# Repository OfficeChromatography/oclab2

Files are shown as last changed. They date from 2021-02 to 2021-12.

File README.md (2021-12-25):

# OCLab2
## Next Generation Office Chromatography

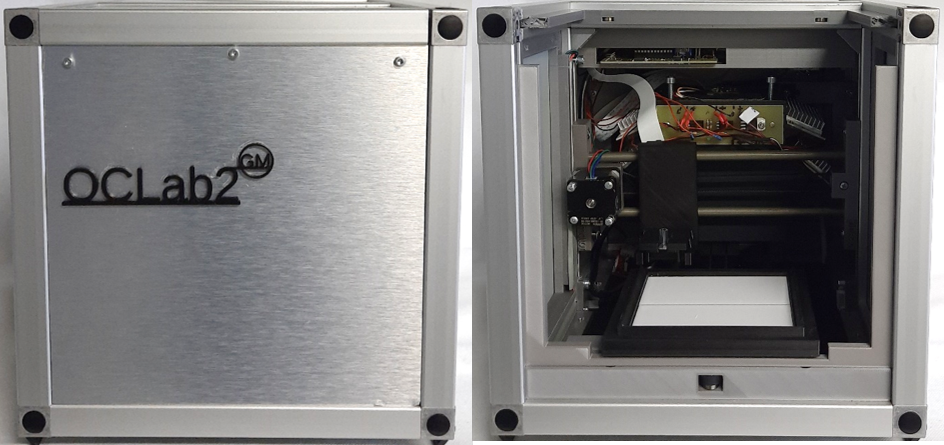
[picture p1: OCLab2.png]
OCLab2


The former [OCLab prototype](https://github.com/OfficeChromatography/OCLab) of a “miniaturized all-in-one open
 source system for planar chromatography” was upgraded by an HPTLC plate visualizing cabinet to protect the 
 plate from extraneous light during capturing of images, including RGBW, UV 278 nm and UV 366 nm LED boards 
 as well as a Raspberry Pi V2 camera module. 
 
 Additionally, a newly designed printhead was manufactured, 
 controlled by a self-constructed ink-jet board allowing to check the nozzles’ resistance heating circuit. 
 Furthermore, plate heating was enabled, especially favorable when higher volumes of aqueous samples are to 
 be applied. 
 
 The former [OC Manager software](https://github.com/OfficeChromatography/OC_manager) was completely 
 restructured and newly written in R to speed-up the processes ([OC_manager2](https://github.com/OfficeChromatography/oc_manager2))
 , also supported by the new Raspberry Pi 4B computer with 4 GB RAM .

### Hardware/Firmware
The 3D printed parts are in the folder 'Construction Set', the electronic boards are described in the folder 
'Eagle Files', and the modified firmware is available in the folder 'Marlin'.
Assembly instructions are in the folder 'Instruction'.

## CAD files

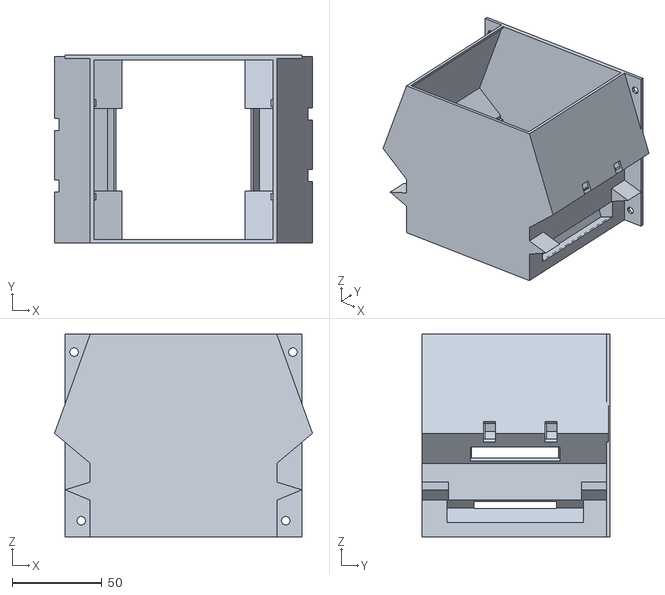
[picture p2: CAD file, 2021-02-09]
Construction Set/camera_tower/STL/camera_tower.stl
143.8 x 105.0 x 113.0

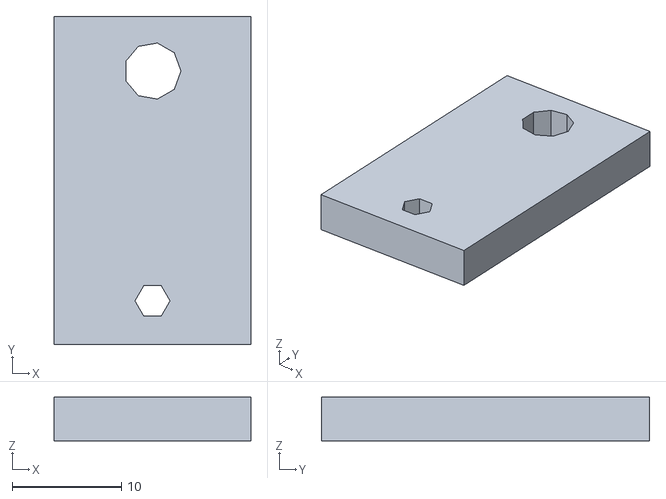
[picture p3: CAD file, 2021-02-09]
Construction Set/connectors/plate_heating_connector.stl
18.0 x 30.0 x 4.00

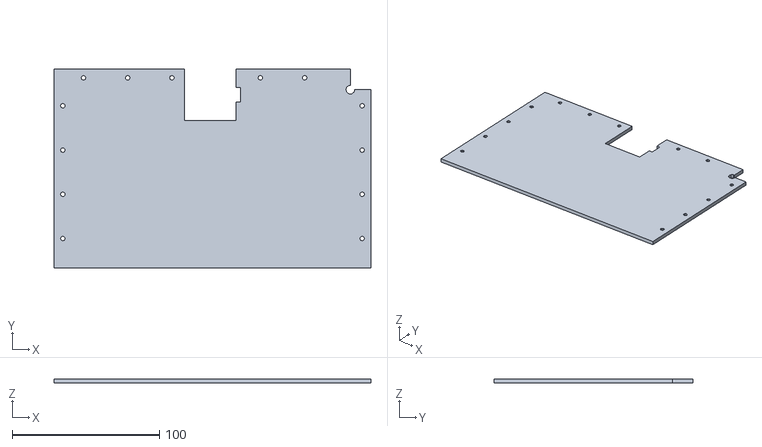
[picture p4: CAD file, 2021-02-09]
Construction Set/faces_frames/STL/bottom_plate_back.stl
215.0 x 135.0 x 3.00

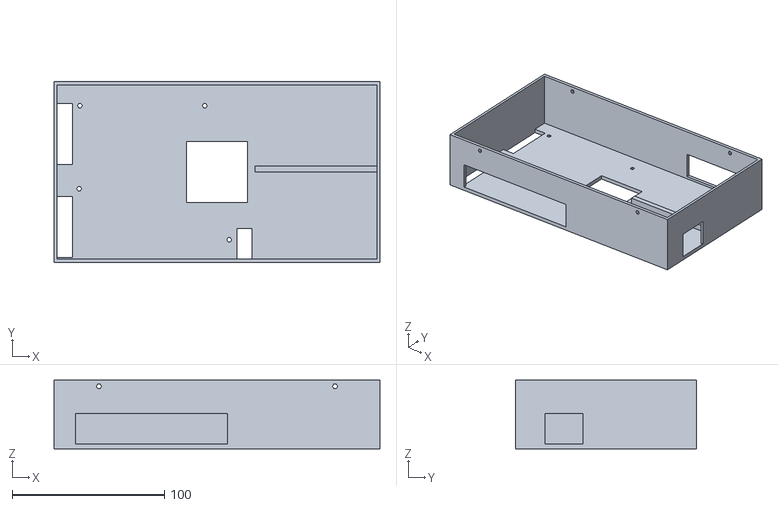
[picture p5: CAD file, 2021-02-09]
Construction Set/housing_electronics/housing_electronics.stl
214.0 x 119.0 x 45.0

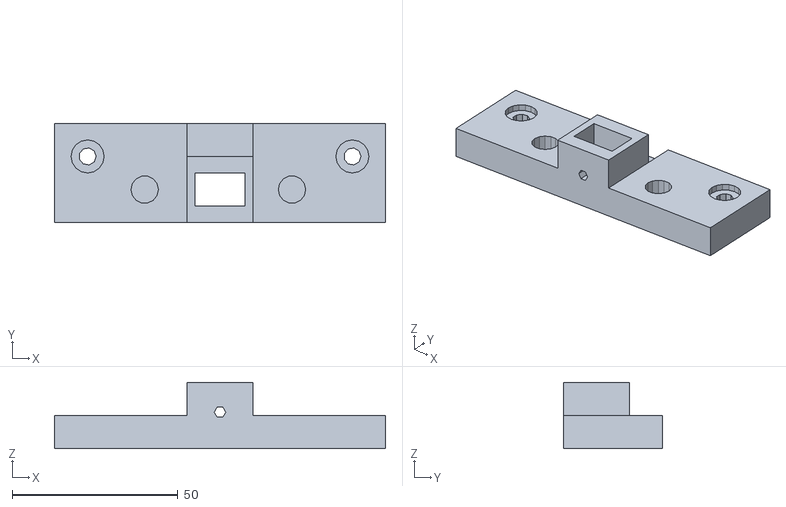
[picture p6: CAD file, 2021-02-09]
Construction Set/X_moving/STL/X_end.stl
100.0 x 30.0 x 20.0

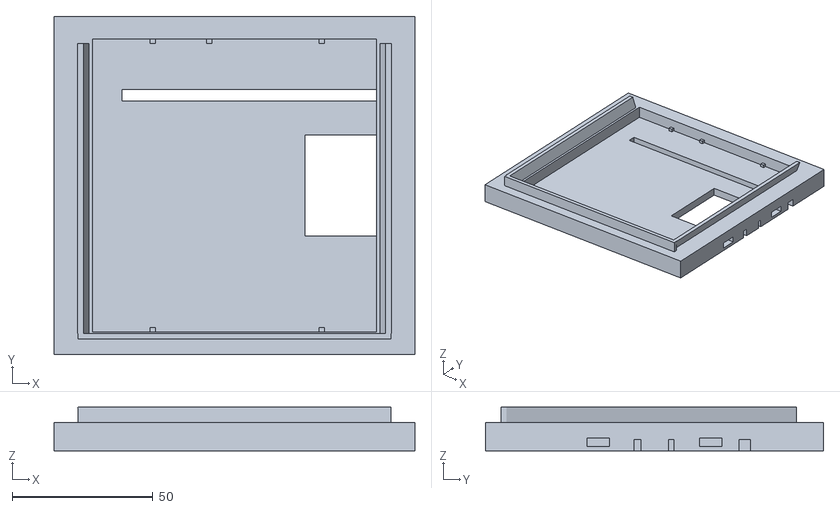
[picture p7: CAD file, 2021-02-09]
Construction Set/Y_moving/STL/plateholder_heating_mat_tower_frame.stl
128.0 x 120.0 x 15.5

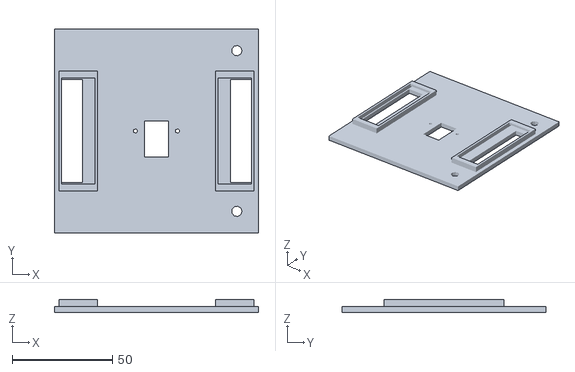
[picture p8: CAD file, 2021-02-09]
Construction Set/camera_tower/STL/camera_holder.stl
101.6 x 101.6 x 6.50

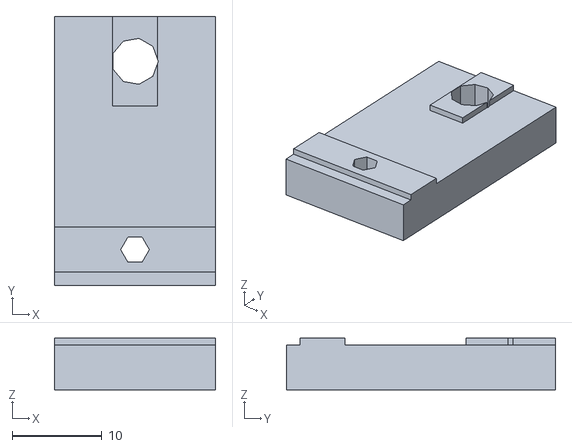
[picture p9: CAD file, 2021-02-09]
Construction Set/connectors/connector_Z_axis_center.stl
18.0 x 30.0 x 5.75

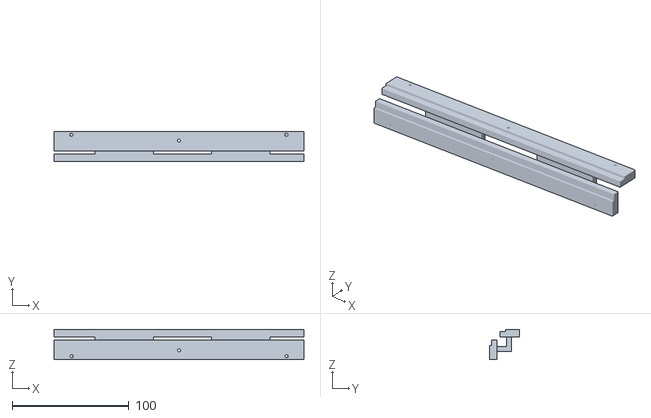
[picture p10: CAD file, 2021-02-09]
Construction Set/faces_frames/STL/cover_mounting.stl
214.0 x 26.0 x 26.0

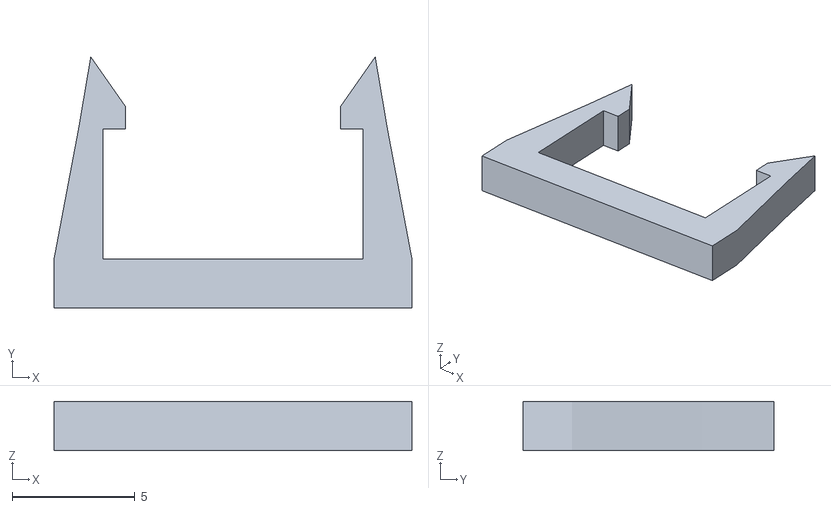
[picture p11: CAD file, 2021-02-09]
Construction Set/X_moving/STL/printhead_clamp.stl
14.6 x 10.2 x 2.00

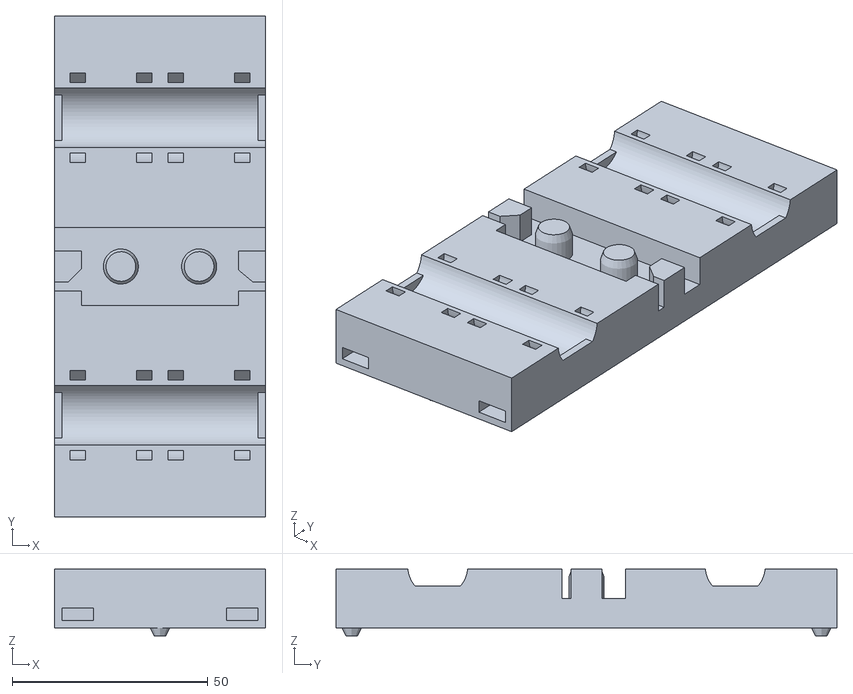
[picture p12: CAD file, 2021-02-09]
Construction Set/Y_moving/STL/Y_moving.stl
54.0 x 128.0 x 17.0

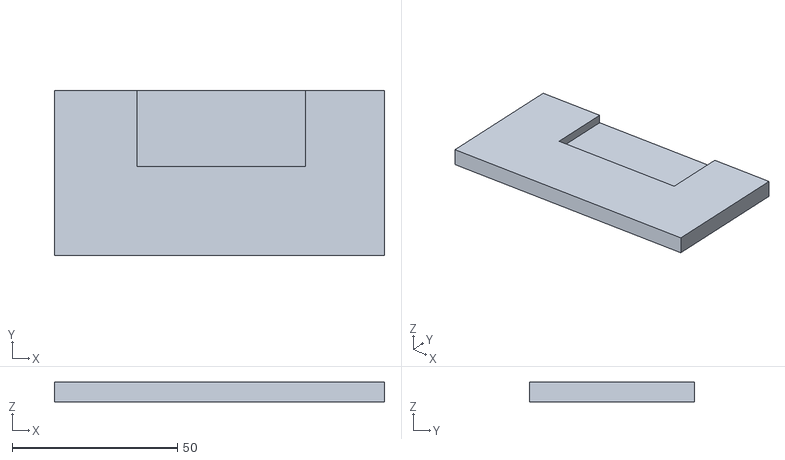
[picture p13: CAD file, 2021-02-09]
Construction Set/camera_tower/STL/cutting_aid_HU02_filter.stl
100.0 x 50.0 x 6.00

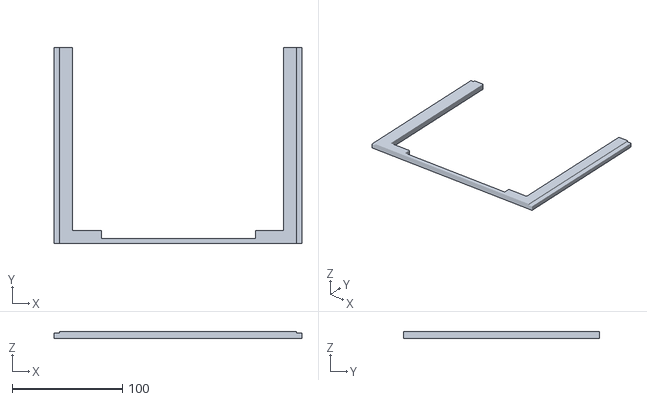
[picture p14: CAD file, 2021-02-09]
Construction Set/faces_frames/STL/front.stl
225.0 x 178.0 x 6.50

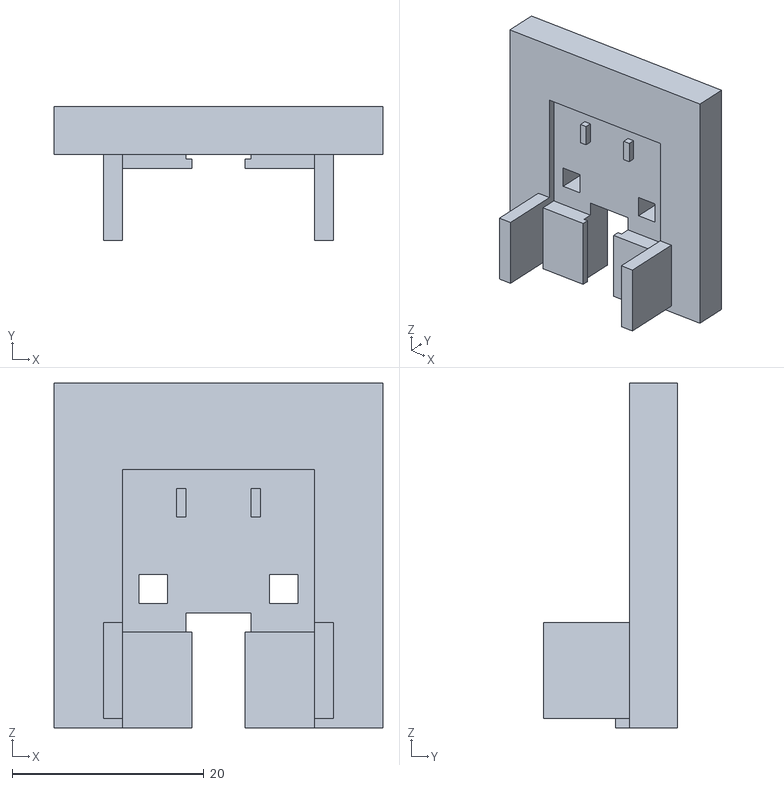
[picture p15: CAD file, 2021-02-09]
Construction Set/X_moving/STL/printhead_top.stl
34.3 x 14.0 x 36.0

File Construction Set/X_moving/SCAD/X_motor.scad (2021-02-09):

// X_motor

difference() {
    start();
    translate([50, 25, 0]) cube([35, 10, 35], center=true);
    translate([27.25,10,4.5])
      cylinder (h = 30, r=4.15); //hole for 8-mm rod
    translate([71.75,10,4.5])
      cylinder (h = 30, r=4.15); //hole for 8-mm rod
    translate([42.5,10,26])
      cube([15,3,9]);
    rotate([90,0,0]) translate([50,17.5,-25])
      cylinder(h=30, r=12.5); //hole for motor
    translate([10,20,-10])
      cylinder (h = 30, r = 2.6); //M5 screw
    translate([90,20,-10])
      cylinder ( h=30, r=2.6); //M5 screw
//Sinkings for M5 screws
    translate([10,20,8])
      cylinder (h=10, r=5);
    translate([90,20,8])
      cylinder (h=10, r=5);
//Screws for motor Nema 14
    rotate([90,0,0]) translate([36.5,4.5,-25])
      cylinder (h=30, r=1.6);
    rotate([90,0,0]) translate([62.5,4.5,-25])
      cylinder (h=30, r=1.6);
    rotate([90,0,0]) translate([36.5,30.5,-25])
      cylinder (h=30, r=1.6);
    rotate([90,0,0]) translate([62.5,30.5,-25])
      cylinder (h=30, r=1.6);
//Sinkings for motor screws
    rotate([90,0,0]) translate([36.5,4.5,-12])
      cylinder (h=20, r=3.5);
    rotate([90,0,0]) translate([62.5,4.5,-12])
      cylinder (h=20, r=3.5);
    rotate([90,0,0]) translate([36.5,30.5,-12])
      cylinder (h=20, r=3.5);
    rotate([90,0,0]) translate([62.5,30.5,-12])
      cylinder (h=20, r=3.5);
//Port for endstop  
    translate([0,11,6])
      cube([22,1.7,4]);
}

module start(){
    cube([100,30,10]);
    translate([32,10,0])
     cube([35,10,35]);
}   

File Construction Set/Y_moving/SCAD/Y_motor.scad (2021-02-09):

// Y_motor Nema 14

x=215;
 
difference() {
    start();
    cube([215, 20, 6]);
    color("yellow", 1.0) {    
    //Holes for rods
    translate([68,10,9.5])
    cylinder (h = 20, r=4.15);
    translate([144, 10, 9.5])
    cylinder (h = 20, r=4.15);
}    
//Hole for motor
color("blue", 1.0 ) {
    rotate([90,0,0])
    translate([109,37.5,-25])
    cylinder(h=30, r=12.5);}
//Holes for M4 screws
color( "black", 1.0) {
    rotate([90,0,0])
    translate([50,10,-30])
    cylinder (h = 40, r = 2.1);
    rotate([90,0,0])
    translate([x-50,10,-30])
    cylinder (h=40, r=2.1);
//Sinkings for M4 screws
    rotate([90,0,0])
    translate([50,10,-6])
    cylinder (h = 6, r=3.6);
    rotate([90,0,0])
    translate([x-50,10,-6])
    cylinder (h=6, r=3.6);    
//Holes for M3 screws, motor mounting
    rotate([90,0,0])
    translate([96,24.5,-25])
    cylinder (h=30, r=1.75);
    rotate([90,0,0])
    translate([122,24.5,-25])
    cylinder (h=30, r=1.75);
    rotate([90,0,0])
    translate([96,50.5,-25])
    cylinder (h=30, r=1.75);
    rotate([90,0,0])
    translate([122,50.5,-25])
    cylinder (h=30, r=1.75); }
//Sinkings for M3 screws
    rotate([90,0,0])
    translate([96,24.5,-13])
    cylinder (h=20, r=3.5);
    rotate([90,0,0])
    translate([122,24.5,-13])
    cylinder (h=20, r=3.5);
    rotate([90,0,0])
    translate([96,50.5,-13])
    cylinder (h=20, r=3.5);
    rotate([90,0,0])
    translate([122,50.5,-13])
    cylinder (h=20, r=3.5);
}
module start(){
cube([215,20,20]);
        color( "red", 1.0 ){
        translate([91.5,10,20])
        cube([35,10,35]);}
}  

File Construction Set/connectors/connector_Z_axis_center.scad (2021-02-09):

//Connector Z_axis center

difference() {
    start();
        translate([0, -11, -5])
        cylinder (h=10, r=1.6);
    translate([0, 10, -5])
    cylinder (h=10, r=2.6);
}
module start() {
    cube([18, 30, 5], center = true);
        translate([0, -11, 2.5])
        cube([18, 5, 1.5], center=true);
        translate([0, 10, 2.5])
        rotate([0, 0, 90])
        cube([10, 5, 1.5], center=true);
    }

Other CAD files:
Construction Set/Y_moving/STL/tower_distance_check.stl
Construction Set/camera_tower/STL/mounting_frame.stl
Construction Set/faces_frames/STL/back_top.stl
Construction Set/X_moving/STL/X_moving.stl
Construction Set/connectors/plate_heating_connector.scad
Construction Set/X_moving/SCAD/HelpMethods/AntiSupport.scad
Construction Set/X_moving/SCAD/HelpMethods/SnapLib.0.36.scad
Construction Set/X_moving/SCAD/HelpMethods/bearing.scad
Construction Set/X_moving/SCAD/HelpMethods/bearing_hor.scad
Construction Set/X_moving/SCAD/HelpMethods/beltholder.scad
Construction Set/X_moving/SCAD/HelpMethods/holder_triangle.scad
Construction Set/X_moving/SCAD/HelpMethods/polyholes.scad
Construction Set/X_moving/SCAD/HelpMethods/supporting_material.scad
Construction Set/X_moving/SCAD/HelpMethods/triangle.scad
Construction Set/X_moving/SCAD/X_end.scad
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

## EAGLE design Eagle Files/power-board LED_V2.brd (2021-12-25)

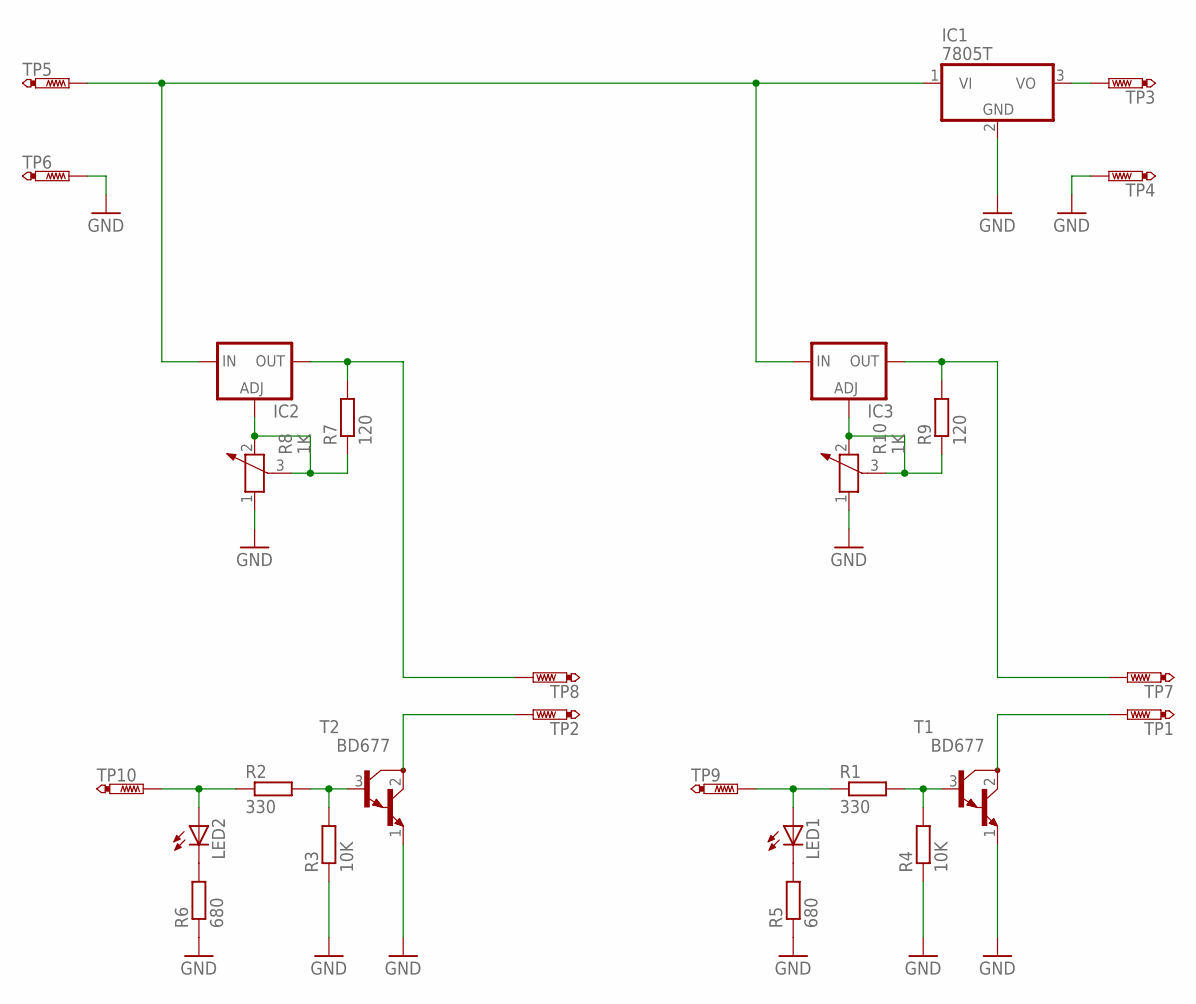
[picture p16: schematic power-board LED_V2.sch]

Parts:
IC1: 7805T; TO220H
IC2, IC3: LM317TS; 317TS
LED1, LED2: LED3MM
R1, R2: 330; 0207/10
R3, R4: 10K; 0207/10
R5, R6: 680; 0207/10
R7, R9: 120; 0207/10
R8, R10: 1K; PT-10
T1, T2: BD677; TO126
TP1, TP2, TP3, TP4, TP5, TP6, TP7, TP8, TP9, TP10: PTR1PAD1-17; P1-17

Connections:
GND: IC1.2 (GND), R3.1, R4.1, R5.1, R6.1, R8.1, R10.1, T1.1 (E), T2.1 (E), TP4.TP, TP6.TP
unnamed: R1.2, R4.2, T1.3 (B)
unnamed: LED1.A, R1.1, TP9.TP
unnamed: T1.2 (C), TP1.TP
unnamed: R2.2, R3.2, T2.3 (B)
unnamed: LED2.A, R2.1, TP10.TP
unnamed: T2.2 (C), TP2.TP
unnamed: IC1.3 (VO), TP3.TP
unnamed: LED1.K (C), R5.2
unnamed: LED2.K (C), R6.2
unnamed: IC2.1 (ADJ), R7.1, R8.2, R8.3
unnamed: IC3.1 (ADJ), R9.1, R10.2, R10.3
unnamed: IC3.2 (OUT), R9.2, TP7.TP
unnamed: IC2.2 (OUT), R7.2, TP8.TP
unnamed: IC1.1 (VI), IC2.3 (IN), IC3.3 (IN), TP5.TP

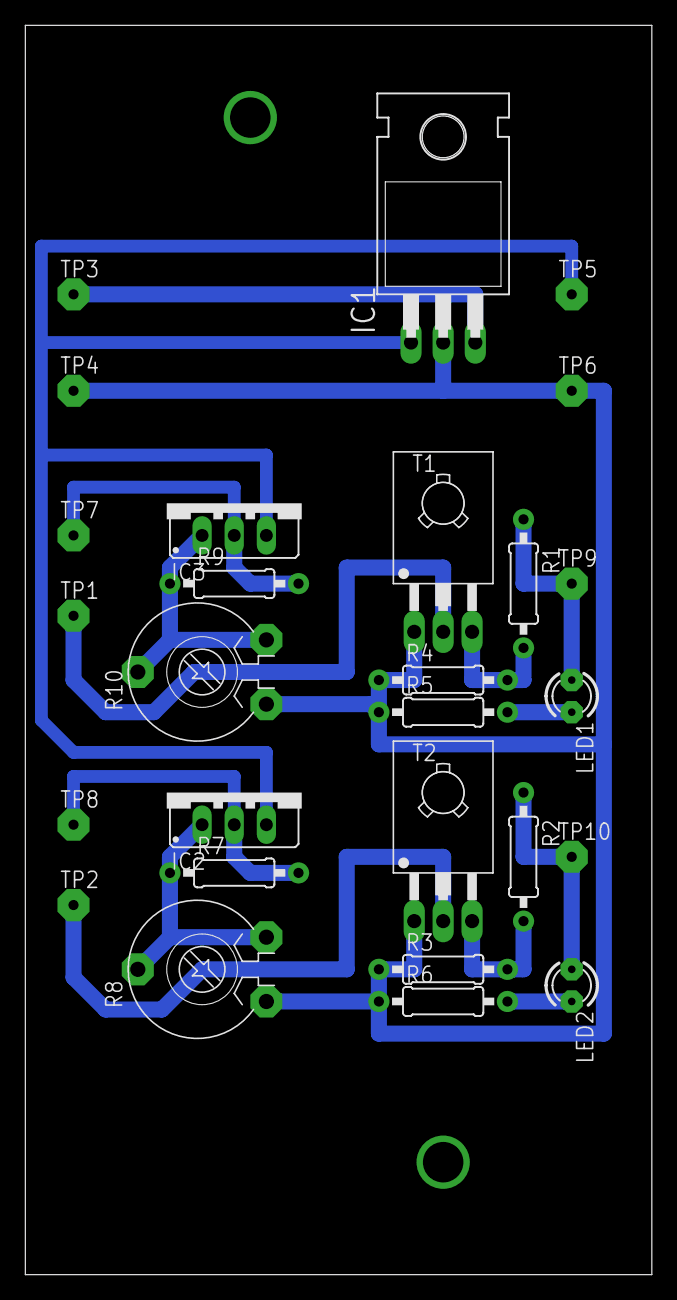
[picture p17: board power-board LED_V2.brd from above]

Board: 2 copper layers, 49.5 x 98.7 mm, 27 parts (0 on the bottom side), 15 nets.

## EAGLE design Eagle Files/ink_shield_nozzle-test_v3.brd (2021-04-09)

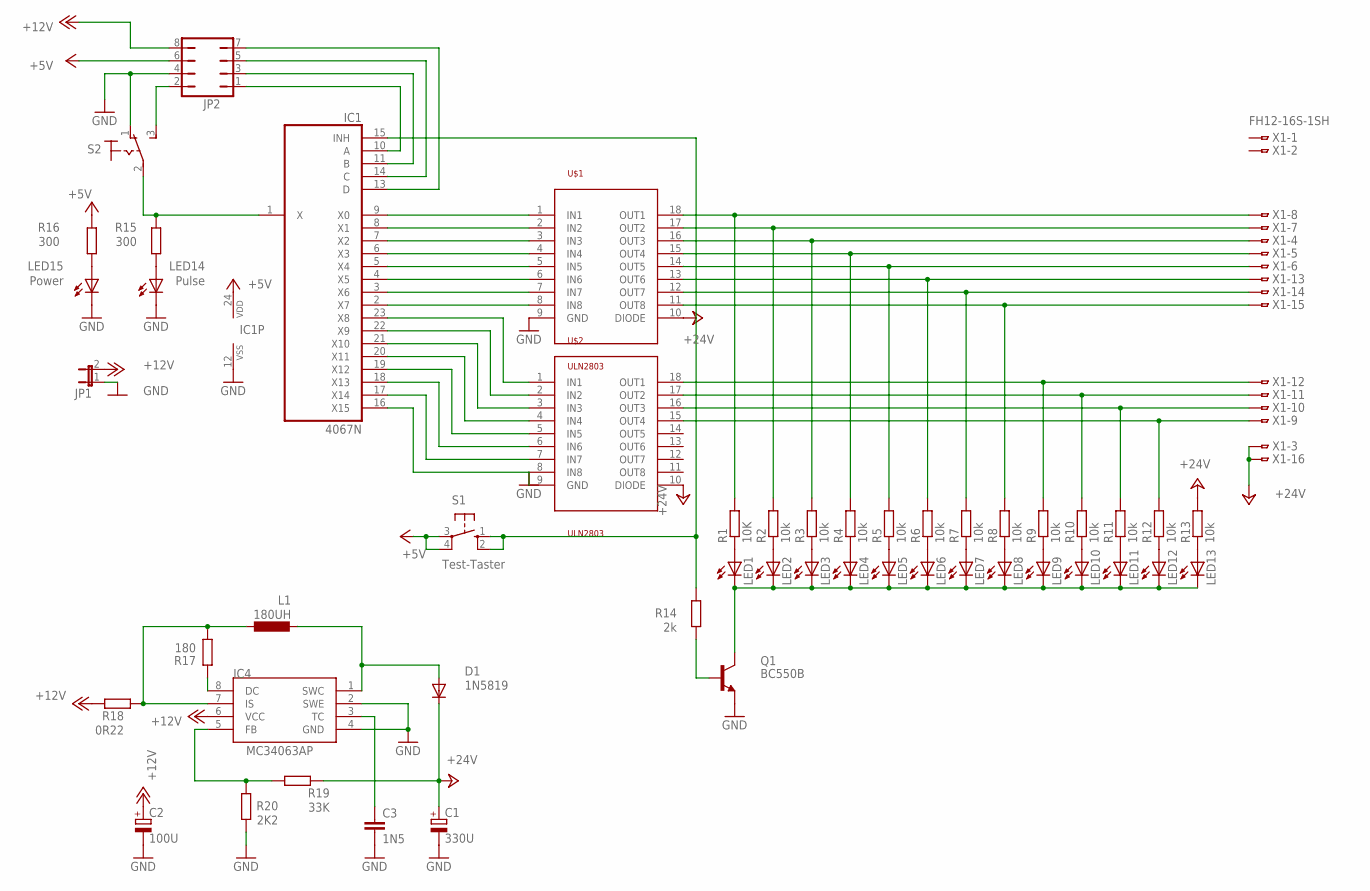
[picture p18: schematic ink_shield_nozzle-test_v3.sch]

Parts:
C1: 330U; E3,5-10
C2: 100U; E2,5-6
C3: 1N5; C025-024X044
D1: 1N5819; DO35-10
IC1: 4067N; DIL24-6
IC4: MC34063AP; DIL08
JP1: JP1E; JP1
JP2: JP4Q
L1: 180UH; 6000-XXXX-RC
LED1, LED2, LED3, LED4, LED5, LED6, LED7, LED8, LED9, LED10, LED11, LED12, LED13: LEDCHIPLED_0603; CHIPLED_0603
LED14: Pulse; LED3MM
LED15: Power; LED3MM
Q1: BC550B; TO92-EBC
R1: 10K; M1206
R2, R3, R4, R5, R6, R7, R8, R9, R10, R11, R12, R13: 10k; M1206
R14: 2k; M3216
R15, R16: 300; 0207/10
R17: 180; 0207/12
R18: 0R22; 0207/12
R19: 33K; 0207/12
R20: 2K2; 0207/10
S1: Test-Taster; B3F-10XX
S2: M9040P
U$1, U$2: ULN2803; SO18L
X1: FH12-16S-1SH

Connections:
+5V: IC1.24 (VDD), JP2.6, R16.2, S1.3, S1.4 (P1)
+12V: C2.+, IC4.6 (VCC), JP1.2, JP2.8, R18.2
+24V: C1.+, D1.C, R13.2, R19.1, U$1.10 (DIODE), U$2.10 (DIODE), X1.3, X1.16
GND: C1.-, C2.-, C3.2, IC1.12 (VSS), IC4.2 (SWE), IC4.4 (GND), JP1.1, JP2.4, LED14.K (C), LED15.K (C), Q1.E, R20.1, S2.1 (O), U$1.9 (GND), U$2.9 (GND)
unnamed: IC1.9 (X0), U$1.1 (IN1)
unnamed: IC1.8 (X1), U$1.2 (IN2)
unnamed: IC1.7 (X2), U$1.3 (IN3)
unnamed: IC1.6 (X3), U$1.4 (IN4)
unnamed: IC1.5 (X4), U$1.5 (IN5)
unnamed: IC1.4 (X5), U$1.6 (IN6)
unnamed: IC1.3 (X6), U$1.7 (IN7)
unnamed: IC1.2 (X7), U$1.8 (IN8)
unnamed: IC1.23 (X8), U$2.1 (IN1)
unnamed: IC1.22 (X9), U$2.2 (IN2)
unnamed: IC1.21 (X10), U$2.3 (IN3)
unnamed: IC1.20 (X11), U$2.4 (IN4)
unnamed: IC1.19 (X12), U$2.5 (IN5)
unnamed: IC1.18 (X13), U$2.6 (IN6)
unnamed: IC1.17 (X14), U$2.7 (IN7)
unnamed: IC1.16 (X15), U$2.8 (IN8)
unnamed: LED1.A, R1.1
unnamed: LED2.A, R2.1
unnamed: LED3.A, R3.1
unnamed: LED4.A, R4.1
unnamed: LED5.A, R5.1
unnamed: LED6.A, R6.1
unnamed: LED7.A, R7.1
unnamed: LED8.A, R8.1
unnamed: LED9.A, R9.1
unnamed: LED10.A, R10.1
unnamed: LED11.A, R11.1
unnamed: LED12.A, R12.1
unnamed: LED1.C, LED2.C, LED3.C, LED4.C, LED5.C, LED6.C, LED7.C, LED8.C, LED9.C, LED10.C, LED11.C, LED12.C, LED13.C, Q1.C
unnamed: R1.2, U$1.18 (OUT1), X1.8
unnamed: R2.2, U$1.17 (OUT2), X1.7
unnamed: R3.2, U$1.16 (OUT3), X1.4
unnamed: R4.2, U$1.15 (OUT4), X1.5
unnamed: R5.2, U$1.14 (OUT5), X1.6
unnamed: R6.2, U$1.13 (OUT6), X1.13
unnamed: R7.2, U$1.12 (OUT7), X1.14
unnamed: R8.2, U$1.11 (OUT8), X1.15
unnamed: R9.2, U$2.18 (OUT1), X1.12
unnamed: R10.2, U$2.17 (OUT2), X1.11
unnamed: R11.2, U$2.16 (OUT3), X1.10
unnamed: R12.2, U$2.15 (OUT4), X1.9
unnamed: LED13.A, R13.1
unnamed: IC1.15 (INH), R14.2, S1.1 (S), S1.2 (S1)
unnamed: Q1.B, R14.1
unnamed: LED14.A, R15.1
unnamed: IC1.10 (A), JP2.1
unnamed: IC1.11 (B), JP2.3
unnamed: IC1.14 (C), JP2.5
unnamed: IC1.13 (D), JP2.7
unnamed: IC1.1 (X), R15.2, S2.2
unnamed: LED15.A, R16.1
unnamed: IC4.7 (IS), L1.1, R17.2, R18.1
unnamed: D1.A, IC4.1 (SWC), L1.2
unnamed: IC4.8 (DC), R17.1
unnamed: C3.1, IC4.3 (TC)
unnamed: IC4.5 (FB), R19.2, R20.2
unnamed: JP2.2, S2.3 (S)

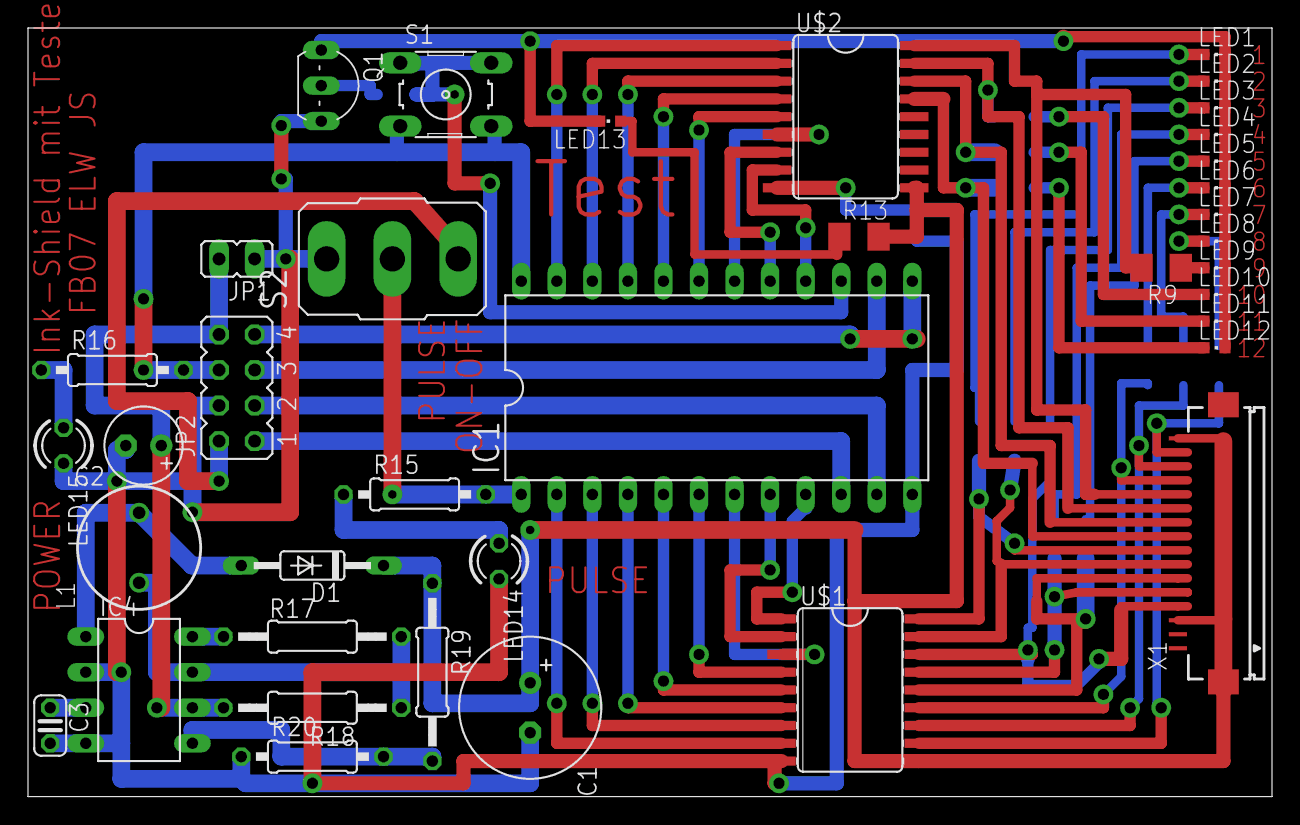
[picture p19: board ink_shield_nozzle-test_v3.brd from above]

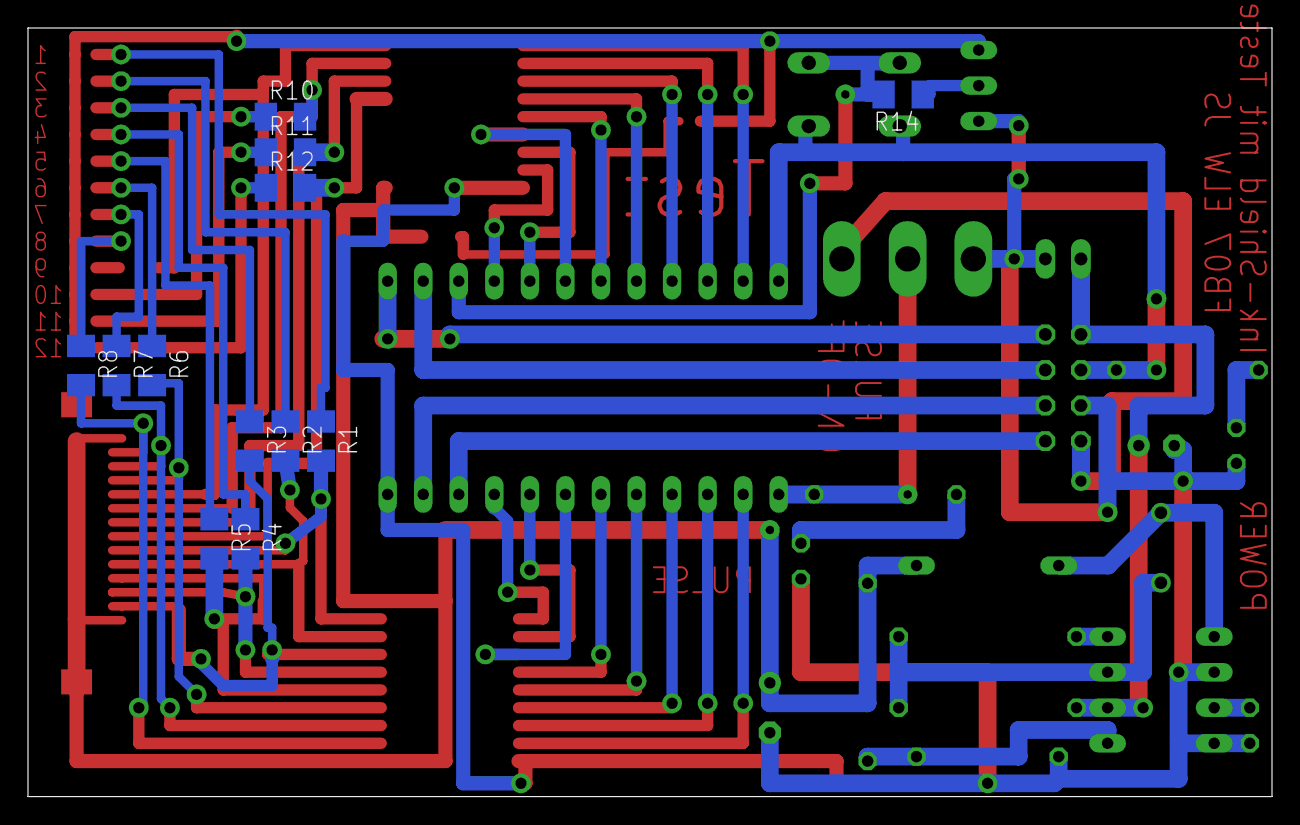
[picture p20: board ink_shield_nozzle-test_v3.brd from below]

Board: 2 copper layers, 88.9 x 54.9 mm, 50 parts (12 on the bottom side), 61 nets.

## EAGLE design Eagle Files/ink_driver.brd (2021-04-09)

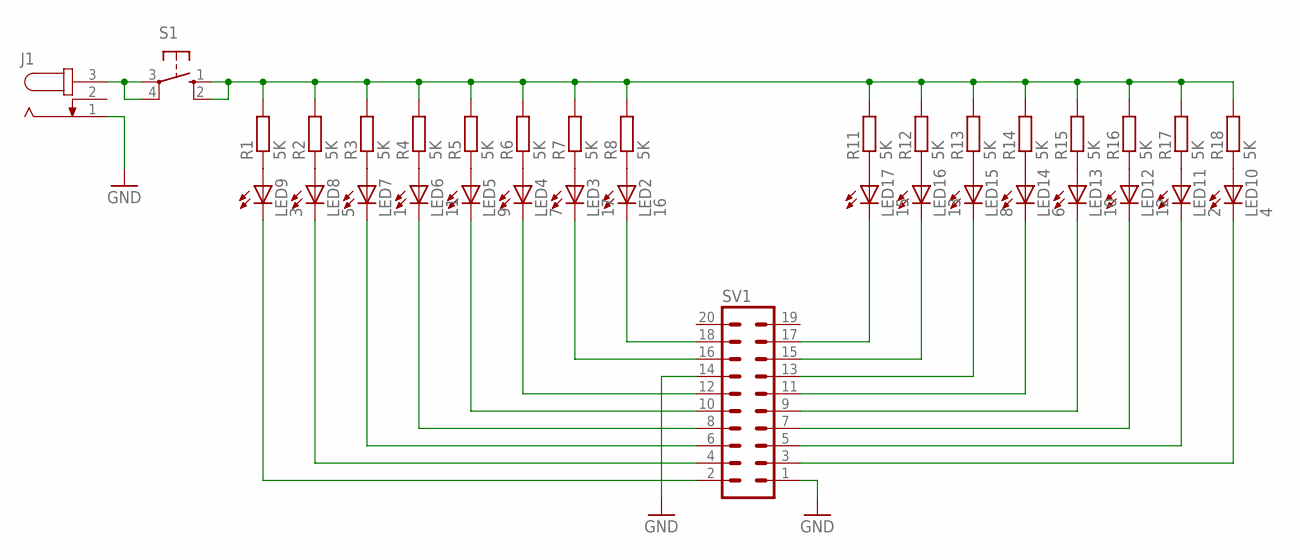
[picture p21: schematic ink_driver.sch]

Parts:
J1: JACK-PLUG1; SPC4078
LED2: 16; LED3MM
LED3: 17; LED3MM
LED4: 7; LED3MM
LED5: 9; LED3MM
LED6: 11; LED3MM
LED7: 1; LED3MM
LED8: 5; LED3MM
LED9: 3; LED3MM
LED10: 4; LED3MM
LED11: 2; LED3MM
LED12: 12; LED3MM
LED13: 10; LED3MM
LED14: 6; LED3MM
LED15: 8; LED3MM
LED16: 13; LED3MM
LED17: 15; LED3MM
R1, R2, R3, R4, R5, R6, R7, R8, R11, R12, R13, R14, R15, R16, R17, R18: 5K; 0207/10
S1: 10-XX; B3F-10XX
SV1: ML20

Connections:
GND: J1.1, SV1.1, SV1.14
unnamed: LED2.K (C), SV1.18
unnamed: LED3.K (C), SV1.16
unnamed: LED4.K (C), SV1.12
unnamed: LED5.K (C), SV1.10
unnamed: LED6.K (C), SV1.8
unnamed: LED7.K (C), SV1.6
unnamed: LED8.K (C), SV1.4
unnamed: LED9.K (C), SV1.2
unnamed: LED9.A, R1.1
unnamed: LED8.A, R2.1
unnamed: LED7.A, R3.1
unnamed: LED6.A, R4.1
unnamed: LED5.A, R5.1
unnamed: LED4.A, R6.1
unnamed: LED3.A, R7.1
unnamed: LED2.A, R8.1
unnamed: LED17.A, R11.1
unnamed: LED16.A, R12.1
unnamed: LED15.A, R13.1
unnamed: LED14.A, R14.1
unnamed: LED13.A, R15.1
unnamed: LED12.A, R16.1
unnamed: LED11.A, R17.1
unnamed: LED10.A, R18.1
unnamed: LED17.K (C), SV1.17
unnamed: LED16.K (C), SV1.15
unnamed: LED15.K (C), SV1.13
unnamed: LED14.K (C), SV1.11
unnamed: LED13.K (C), SV1.9
unnamed: LED12.K (C), SV1.7
unnamed: LED11.K (C), SV1.5
unnamed: LED10.K (C), SV1.3
unnamed: R1.2, R2.2, R3.2, R4.2, R5.2, R6.2, R7.2, R8.2, R11.2, R12.2, R13.2, R14.2, R15.2, R16.2, R17.2, R18.2, S1.1 (S), S1.2 (S1)
unnamed: J1.3, S1.3, S1.4 (P1)

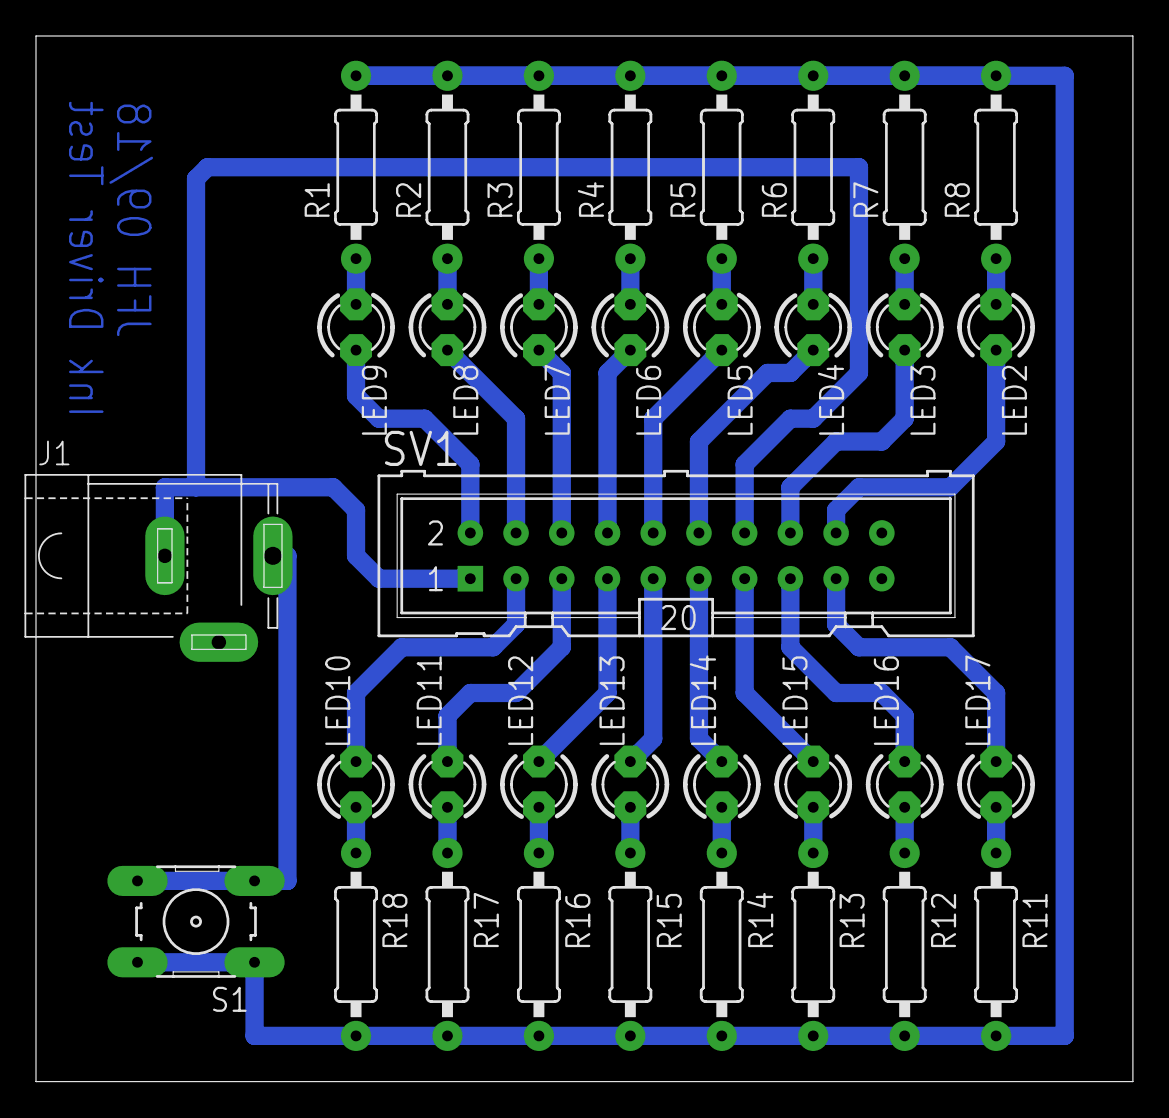
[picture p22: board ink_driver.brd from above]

Board: 2 copper layers, 60.9 x 58.1 mm, 35 parts (0 on the bottom side), 35 nets.

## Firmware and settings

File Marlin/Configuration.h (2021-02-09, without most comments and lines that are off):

#define CONFIGURATION_H
#define STRING_VERSION_CONFIG_H __DATE__ " " __TIME__ // build date and time
#define STRING_CONFIG_H_AUTHOR "(none, default config)" // Who made the changes.
#define SERIAL_PORT 0
#define BAUDRATE 115200
#define MOTHERBOARD 33
#define EXTRUDERS 1
#define POWER_SUPPLY 1
#define DELTA_SEGMENTS_PER_SECOND 200
#define DELTA_DIAGONAL_ROD 250.0 // mm
#define DELTA_SMOOTH_ROD_OFFSET 175.0 // mm
#define DELTA_EFFECTOR_OFFSET 33.0 // mm
#define DELTA_CARRIAGE_OFFSET 18.0 // mm
#define DELTA_RADIUS (DELTA_SMOOTH_ROD_OFFSET-DELTA_EFFECTOR_OFFSET-DELTA_CARRIAGE_OFFSET)
#define SIN_60 0.8660254037844386
#define COS_60 0.5
#define DELTA_TOWER1_X -SIN_60*DELTA_RADIUS // front left tower
#define DELTA_TOWER1_Y -COS_60*DELTA_RADIUS
#define DELTA_TOWER2_X SIN_60*DELTA_RADIUS // front right tower
#define DELTA_TOWER2_Y -COS_60*DELTA_RADIUS
#define DELTA_TOWER3_X 0.0 // back middle tower
#define DELTA_TOWER3_Y DELTA_RADIUS
#define TEMP_SENSOR_0 0
#define TEMP_SENSOR_1 0
#define TEMP_SENSOR_2 0
#define TEMP_SENSOR_BED 10
#define MAX_REDUNDANT_TEMP_SENSOR_DIFF 10
#define TEMP_RESIDENCY_TIME 10  // (seconds)
#define TEMP_HYSTERESIS 3       // (degC) range of +/- temperatures considered "close" to the target one
#define TEMP_WINDOW     1       // (degC) Window around target to start the residency timer x degC early.
#define HEATER_0_MINTEMP 5
#define BED_MINTEMP 5
#define HEATER_0_MAXTEMP 110
#define BED_MAXTEMP 60
#define PIDTEMP
#define BANG_MAX 255 // limits current to nozzle while in bang-bang mode; 255=full current
#define PID_MAX 255 // limits current to nozzle while PID is active (see PID_FUNCTIONAL_RANGE below); 255=full current
  #define PID_FUNCTIONAL_RANGE 10 // If the temperature difference between the target temperature and the actual temperature
  #define PID_INTEGRAL_DRIVE_MAX 255  //limit for the integral term
  #define K1 0.95 //smoothing factor within the PID
  #define PID_dT ((16.0 * 8.0)/(F_CPU / 64.0 / 256.0)) //sampling period of the temperature routine
    #define  DEFAULT_Kp 22.2
    #define  DEFAULT_Ki 1.08
    #define  DEFAULT_Kd 114
#define PIDTEMPBED
#define MAX_BED_POWER 255 // limits duty cycle to bed; 255=full current
    #define  DEFAULT_bedKp 59.84
    #define  DEFAULT_bedKi 3.31
    #define  DEFAULT_bedKd 722.27
#define ENDSTOPPULLUPS // Comment this out (using // at the start of the line) to disable the endstop pullup resistors
  #define ENDSTOPPULLUP_XMAX
  #define ENDSTOPPULLUP_YMAX
  #define ENDSTOPPULLUP_ZMAX
  #define ENDSTOPPULLUP_XMIN
  #define ENDSTOPPULLUP_YMIN
  #define ENDSTOPPULLUP_ZMIN
const bool X_ENDSTOPS_INVERTING = true; // set to true to invert the logic of the endstops.
const bool Y_ENDSTOPS_INVERTING = true; // set to true to invert the logic of the endstops.
const bool Z_ENDSTOPS_INVERTING = true; // set to true to invert the logic of the endstops.
#if defined(COREXY) && !defined(DISABLE_MAX_ENDSTOPS)
  #define DISABLE_MAX_ENDSTOPS
#endif
#define X_ENABLE_ON 0
#define Y_ENABLE_ON 0
#define Z_ENABLE_ON 0
#define E_ENABLE_ON 0 // For all extruders
#define DISABLE_X false
#define DISABLE_Y false
#define DISABLE_Z false
#define DISABLE_E false // For all extruders
#define INVERT_X_DIR true    // for Mendel set to false, for Orca set to true
#define INVERT_Y_DIR false    // for Mendel set to true, for Orca set to false
#define INVERT_Z_DIR true     // for Mendel set to false, for Orca set to true
#define INVERT_E0_DIR false   // for direct drive extruder v9 set to true, for geared extruder set to false
#define INVERT_E1_DIR false    // for direct drive extruder v9 set to true, for geared extruder set to false
#define INVERT_E2_DIR false   // for direct drive extruder v9 set to true, for geared extruder set to false
#define X_HOME_DIR -1
#define Y_HOME_DIR -1
#define Z_HOME_DIR -1
#define min_software_endstops true // If true, axis won't move to coordinates less than HOME_POS.
#define max_software_endstops true  // If true, axis won't move to coordinates greater than the defined lengths below.
#define X_MAX_POS 135
#define X_MIN_POS 0
#define Y_MAX_POS 164
#define Y_MIN_POS 0
#define Z_MAX_POS 200 // no Z yet
#define Z_MIN_POS 0
#define X_MAX_LENGTH (X_MAX_POS - X_MIN_POS)
#define Y_MAX_LENGTH (Y_MAX_POS - Y_MIN_POS)
#define Z_MAX_LENGTH (Z_MAX_POS - Z_MIN_POS)
#define MANUAL_X_HOME_POS 0
#define MANUAL_Y_HOME_POS 0
#define MANUAL_Z_HOME_POS 0
#define NUM_AXIS 4 // The axis order in all axis related arrays is X, Y, Z, E
#define HOMING_FEEDRATE {50*60, 50*60, 2*60, 0}  // set the homing speeds (mm/min)
#define DEFAULT_AXIS_STEPS_PER_UNIT   {80,80,4000,400}  // default steps per unit for Ultimaker // 400 for old tr8
#define DEFAULT_MAX_FEEDRATE          {100, 100, 2, 13}    // (mm/sec)
#define DEFAULT_MAX_ACCELERATION      {400,400,20,1000}    // X, Y, Z, E maximum start speed for accelerated moves. E default values are good for skeinforge 40+, for older versions raise them a lot.
#define DEFAULT_ACCELERATION          2000    // X, Y, Z and E max acceleration in mm/s^2 for printing moves
#define DEFAULT_RETRACT_ACCELERATION  2000   // X, Y, Z and E max acceleration in mm/s^2 for retracts
#define DEFAULT_XYJERK                20.0    // (mm/sec)
#define DEFAULT_ZJERK                 0.4     // (mm/sec)
#define DEFAULT_EJERK                 5.0    // (mm/sec)
#define EEPROM_SETTINGS
#define EEPROM_CHITCHAT
#define PLA_PREHEAT_HOTEND_TEMP 180
#define PLA_PREHEAT_HPB_TEMP 70
#define PLA_PREHEAT_FAN_SPEED 255   // Insert Value between 0 and 255
#define ABS_PREHEAT_HOTEND_TEMP 240
#define ABS_PREHEAT_HPB_TEMP 100
#define ABS_PREHEAT_FAN_SPEED 255   // Insert Value between 0 and 255
#define SOFT_PWM_SCALE 0
#define HPC6602
#define NUM_HPC6602 1 // Number of Inkjet heads
#define NEOPIXEL_TYPE   NEO_GRBW // NEO_GRBW / NEO_GRB - four/three channel driver type (defined in Adafruit_NeoPixel.h)
#define NEOPIXEL_PIN    66        // LED driving pin on motherboard 4 => D4 (EXP2-5 on Printrboard) / 30 => PC7 (EXP3-13 on Rumba)
#define NEOPIXEL_PIXELS 16       // Number of LEDs in the strip
#define NEOPIXEL_IS_SEQUENTIAL   // Sequential display for temperature change - LED by LED. Disable to change all LEDs at once.
#define NEOPIXEL_BRIGHTNESS 255  // Initial brightness (0-255)
#include "Configuration_adv.h"
#include "thermistortables.h"

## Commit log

2021-04-09 eagle files added
    [278nm-LED-board.brd, 365nm-LED-board.brd, LED_power-supply.brd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]
2021-12-25 Eagle files new
    [LED_power-supply.brd, LED_power-supply.sch, power-board LED_V2.brd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]
